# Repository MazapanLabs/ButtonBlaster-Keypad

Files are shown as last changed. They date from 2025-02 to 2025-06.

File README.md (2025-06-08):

# ButtonBlaster-Keypad

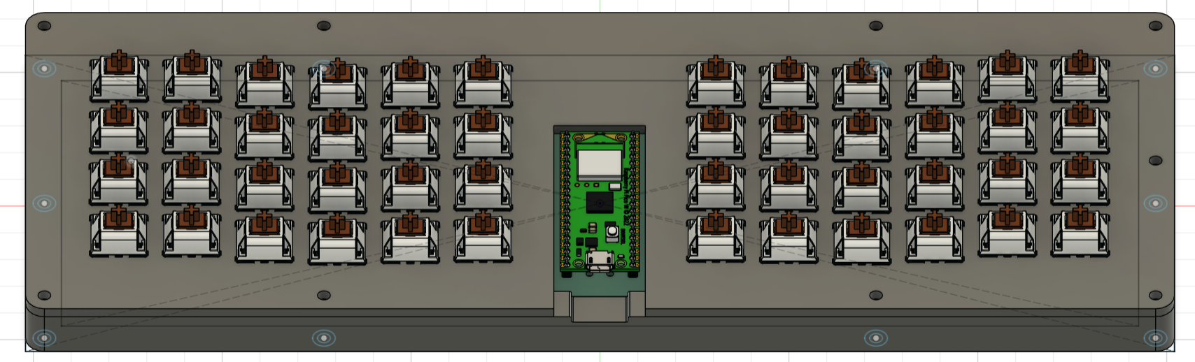
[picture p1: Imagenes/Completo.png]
Model


ButtonBlaster is a compact 48-key keypad based on the Orpheus Pico microcontroller and designed to work with the KMK firmware. The project was inspired by an ergonomic keyboard shown in a video by Joe Scotto. The PCB was custom-designed and paired with a 3D-printed case. It uses Gateron mechanical switches and discrete diodes.

## 🎥 Inspiration

Design inspired by a keyboard featured in a video by Joe Scotto:  
https://youtu.be/sMTs8F6Fk6s?si=EPKrmchUF-LIuJZo

---

## 📦 Specifications

### 🔩 Bill of Materials (BOM)

| Quantity | Component | Link |
|---|---|---|
| 48x | Gateron KS-3X1 Milky Switch | [Keychron](https://www.keychron.mx/products/gateron-ks-3x1-milky-switch?variant=45655197909205) |
| 48x | Keycaps | [Keychron](https://www.keychron.mx/products/keychron-k12-keycap-set?variant=45655109271765) |
| 48x | Diodes 1N4148 | [UElectronics](https://uelectronics.com/producto/kit-de-100-diodos-1n5399-1n5408-1n4148-1n4007-1n5819-1n5822/) |
| 1x | Orpheus Pico | — |
| 1x | Custom PCB | — |
| 10x | M3 brass heatsets | [UElectronics](https://uelectronics.com/producto/rosca-de-laton-m2-m3-m4/) |
| 10x | M3x12 screws | [MercadoLibre](https://articulo.mercadolibre.com.mx/MLM-3383497816-tornillo-m3-de-cruz-12mm-100pzs-_JM) |

### 🧰 Other files

- Firmware: **KMK**
- STL files:
  - `ButtonBlaster-Keypad_Top.stl`
  - `ButtonBlaster-Keypad_Bottom.stl`

---

## 📷 Project Images

### 🔌 Schematic
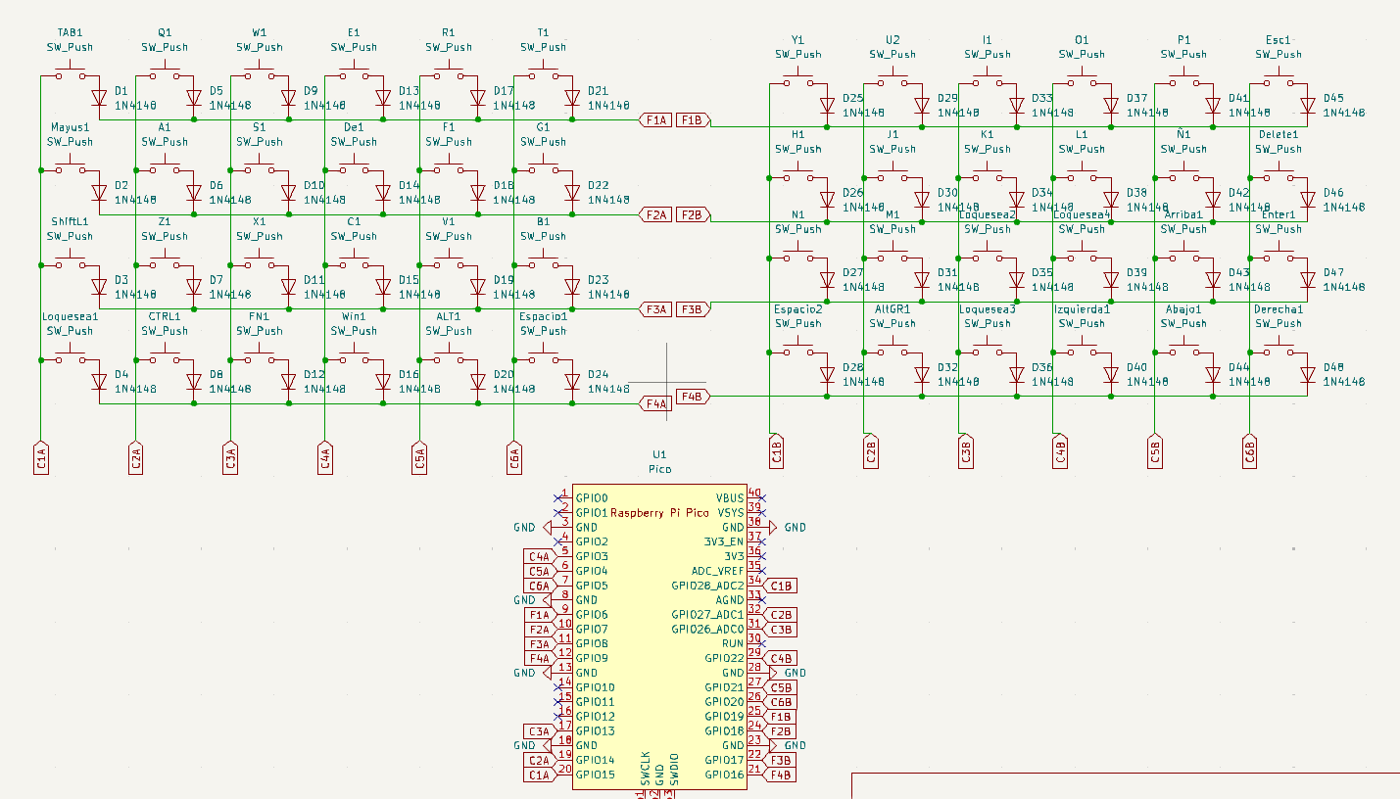
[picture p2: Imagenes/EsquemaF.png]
Schematic


### 🧠 PCB
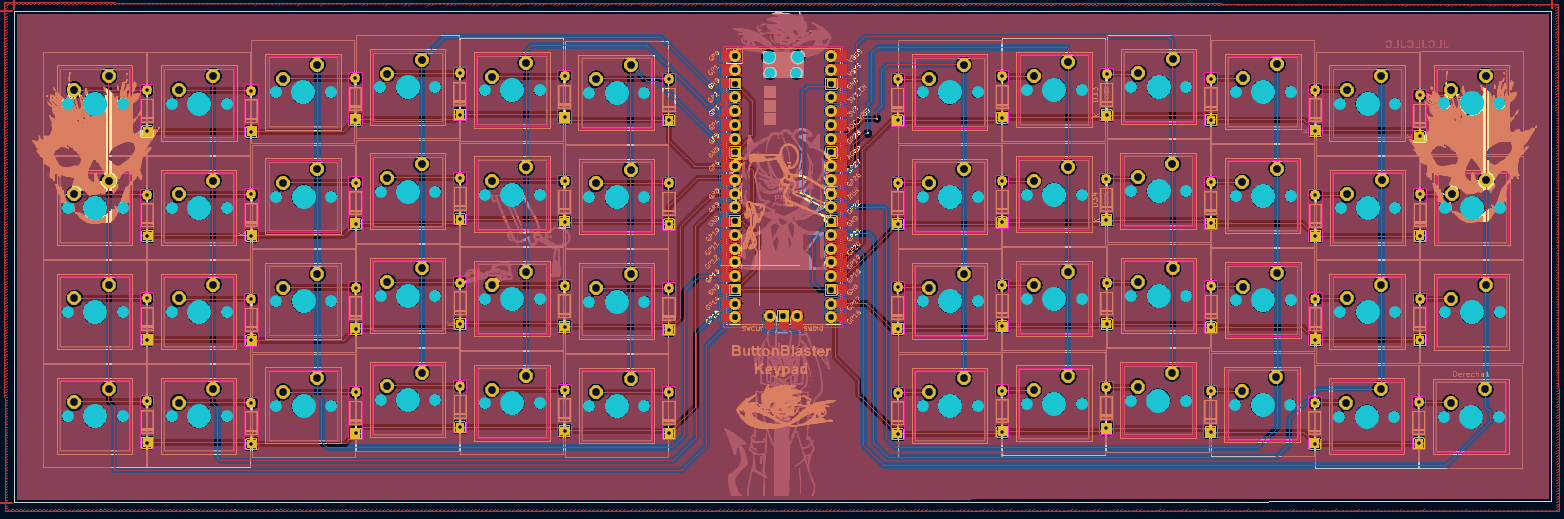
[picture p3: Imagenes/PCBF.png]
PCB


### 🧱 Case
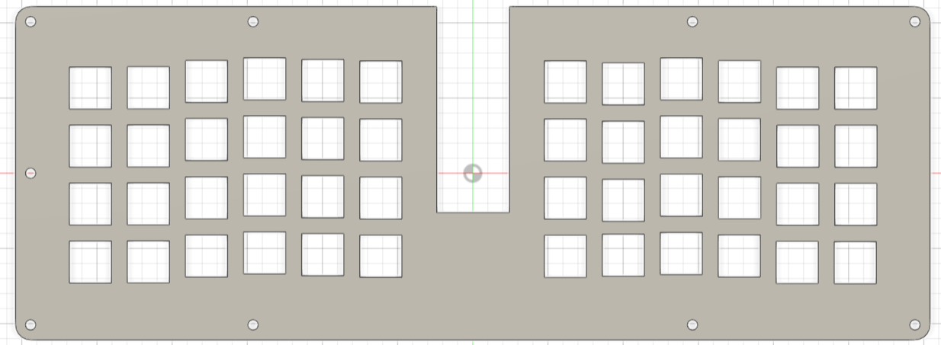
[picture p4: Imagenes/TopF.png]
CaseT

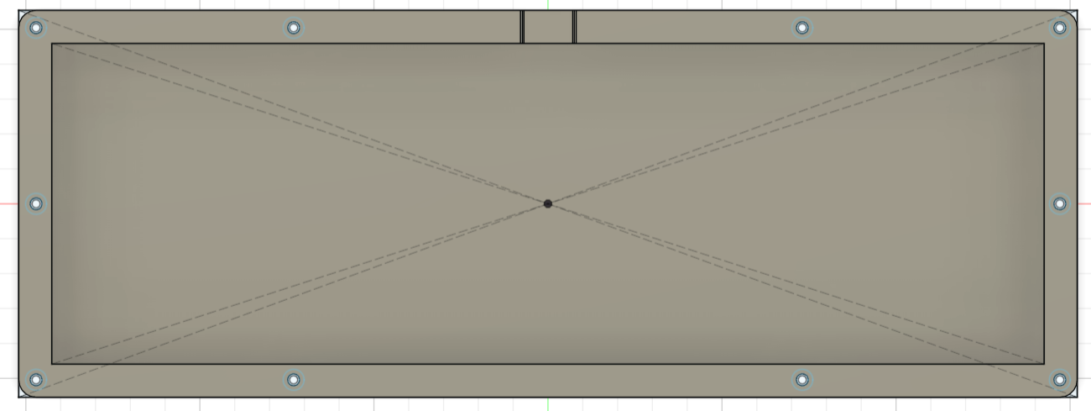
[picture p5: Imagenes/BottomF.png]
CaseB


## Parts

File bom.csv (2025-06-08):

Designator | Footprint | Quantity | Value | LCSC Part #
A1, ABAJO1, ALT1, ALTGR1, ARRIBA1, B1, C1, CTRL1, DE1, DELETE1, DERECHA1, E1, ENTER1, ESC1, ESPACIO1, ESPACIO2, F1, FN1, G1, H1, I1, IZQUIERDA1, J1, K1, L1, LOQUESEA1, LOQUESEA2, LOQUESEA3, LOQUESEA4, M1, MAYUS1, N1, O1, P1, Q1, R1, S1, SHIFTL1, T1, TAB1, U2, V1, W1, WIN1, X1, Y1, Z1, Ñ1 | SW_Cherry_MX_1.00u_PCB | 48 | SW_Push
D1, D10, D11, D12, D13, D14, D15, D16, D17, D18, D19, D2, D20, D21, D22, D23, D24, D25, D26, D27, D28, D29, D3, D30, D31, D32, D33, D34, D35, D36, D37, D38, D39, D4, D40, D41, D42, D43, D44, D45, D46, D47, D48, D5, D6, D7, D8, D9 | D_DO-35_SOD27_P7.62mm_Horizontal | 48 | 1N4148
U1 | RPi_Pico_SMD_TH | 1 | Pico

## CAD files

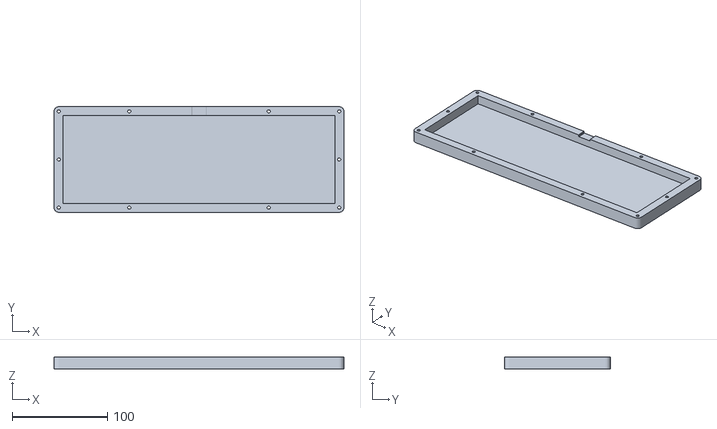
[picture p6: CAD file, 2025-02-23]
Production/BB-K Bottom_.stl
304.1 x 110.8 x 13.0

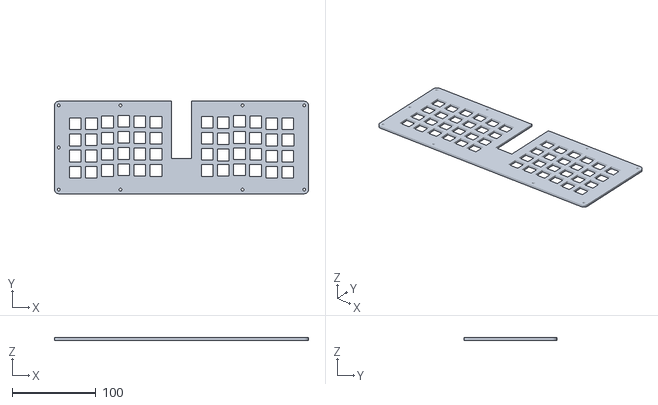
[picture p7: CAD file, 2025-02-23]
Production/BB-K Top.stl
304.1 x 110.8 x 3.00

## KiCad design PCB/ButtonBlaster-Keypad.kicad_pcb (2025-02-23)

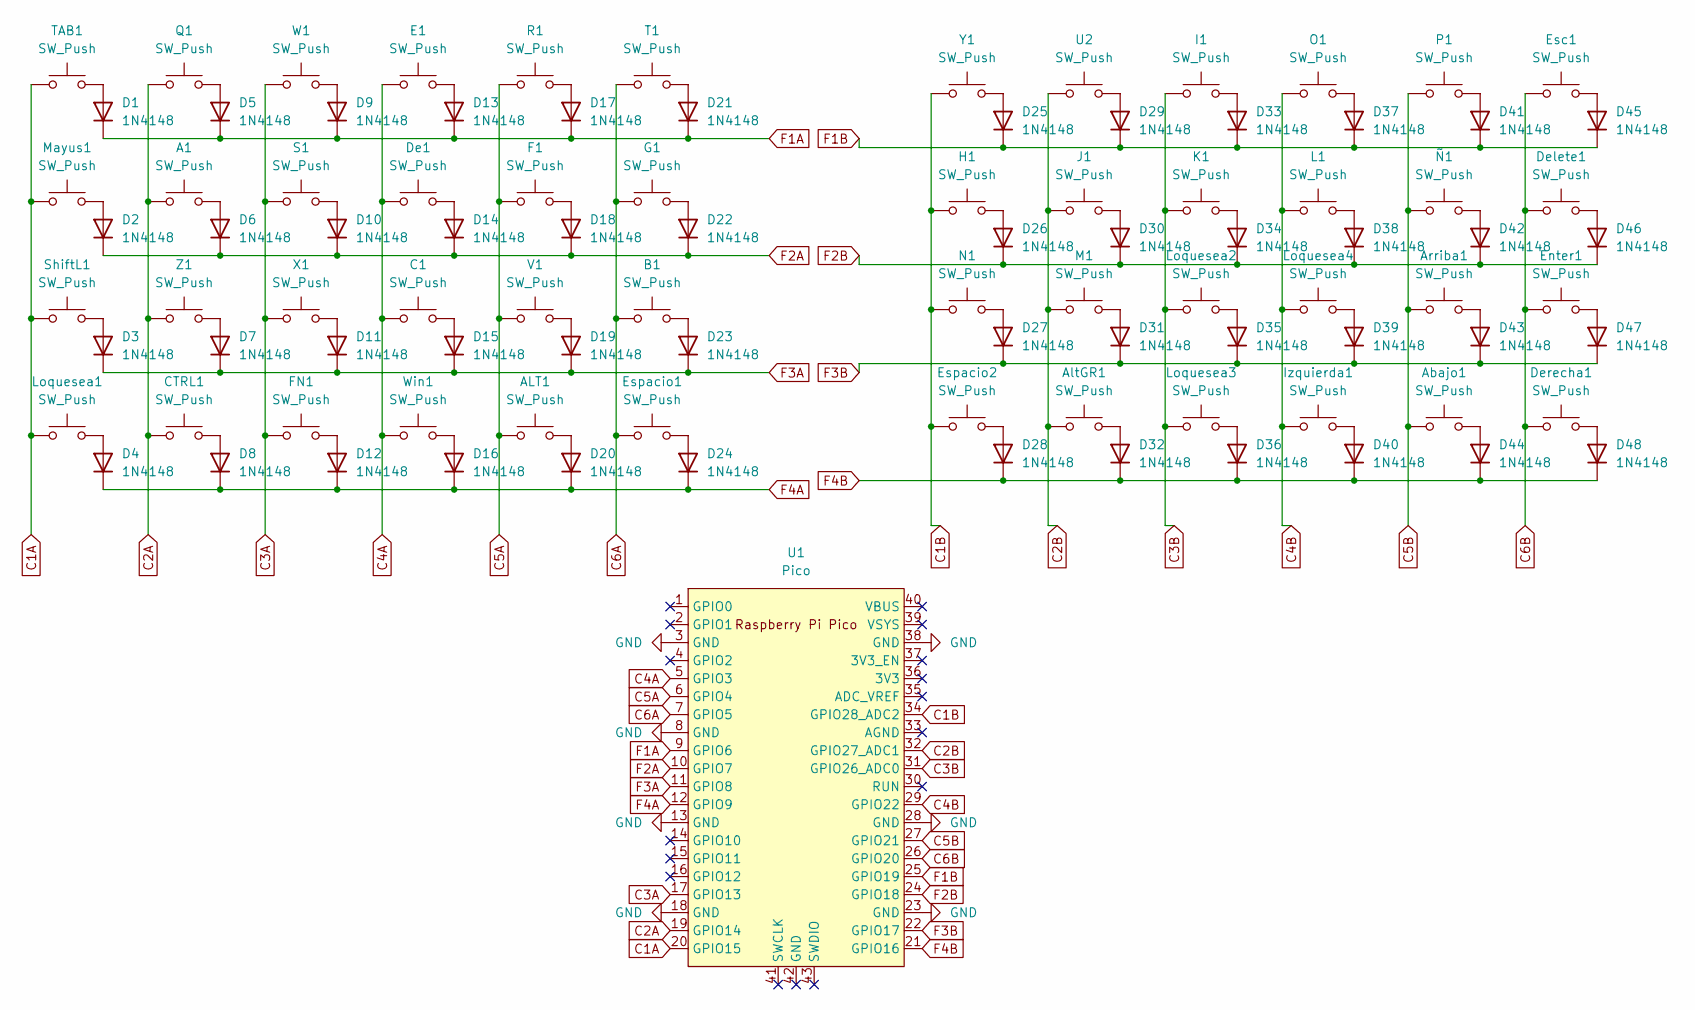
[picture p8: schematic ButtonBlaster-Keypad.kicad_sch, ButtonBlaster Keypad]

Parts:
A1: SW_Push; SW_Cherry_MX_1.00u_PCB
ALT1: SW_Push; SW_Cherry_MX_1.00u_PCB
Abajo1: SW_Push; SW_Cherry_MX_1.00u_PCB
AltGR1: SW_Push; SW_Cherry_MX_1.00u_PCB
Arriba1: SW_Push; SW_Cherry_MX_1.00u_PCB
B1: SW_Push; SW_Cherry_MX_1.00u_PCB
C1: SW_Push; SW_Cherry_MX_1.00u_PCB
CTRL1: SW_Push; SW_Cherry_MX_1.00u_PCB
D1, D2, D3, D4, D5, D6, D7, D8, D9, D10, D11, D12, D13, D14, D15, D16, D17, D18, D19, D20, D21, D22, D23, D24, D25, D26, D27, D28, D29, D30, D31, D32, D33, D34, D35, D36, D37, D38, D39, D40, D41, D42, D43, D44, D45, D46, D47, D48: 1N4148; D_DO-35_SOD27_P7.62mm_Horizontal
De1: SW_Push; SW_Cherry_MX_1.00u_PCB
Delete1: SW_Push; SW_Cherry_MX_1.00u_PCB
Derecha1: SW_Push; SW_Cherry_MX_1.00u_PCB
E1: SW_Push; SW_Cherry_MX_1.00u_PCB
Enter1: SW_Push; SW_Cherry_MX_1.00u_PCB
Esc1: SW_Push; SW_Cherry_MX_1.00u_PCB
Espacio1, Espacio2: SW_Push; SW_Cherry_MX_1.00u_PCB
F1: SW_Push; SW_Cherry_MX_1.00u_PCB
FN1: SW_Push; SW_Cherry_MX_1.00u_PCB
G1: SW_Push; SW_Cherry_MX_1.00u_PCB
H1: SW_Push; SW_Cherry_MX_1.00u_PCB
I1: SW_Push; SW_Cherry_MX_1.00u_PCB
Izquierda1: SW_Push; SW_Cherry_MX_1.00u_PCB
J1: SW_Push; SW_Cherry_MX_1.00u_PCB
K1: SW_Push; SW_Cherry_MX_1.00u_PCB
L1: SW_Push; SW_Cherry_MX_1.00u_PCB
Loquesea1, Loquesea2, Loquesea3, Loquesea4: SW_Push; SW_Cherry_MX_1.00u_PCB
M1: SW_Push; SW_Cherry_MX_1.00u_PCB
Mayus1: SW_Push; SW_Cherry_MX_1.00u_PCB
N1: SW_Push; SW_Cherry_MX_1.00u_PCB
O1: SW_Push; SW_Cherry_MX_1.00u_PCB
P1: SW_Push; SW_Cherry_MX_1.00u_PCB
Q1: SW_Push; SW_Cherry_MX_1.00u_PCB
R1: SW_Push; SW_Cherry_MX_1.00u_PCB
S1: SW_Push; SW_Cherry_MX_1.00u_PCB
ShiftL1: SW_Push; SW_Cherry_MX_1.00u_PCB
T1: SW_Push; SW_Cherry_MX_1.00u_PCB
TAB1: SW_Push; SW_Cherry_MX_1.00u_PCB
U1: Pico; RPi_Pico_SMD_TH
U2: SW_Push; SW_Cherry_MX_1.00u_PCB
V1: SW_Push; SW_Cherry_MX_1.00u_PCB
W1: SW_Push; SW_Cherry_MX_1.00u_PCB
Win1: SW_Push; SW_Cherry_MX_1.00u_PCB
X1: SW_Push; SW_Cherry_MX_1.00u_PCB
Y1: SW_Push; SW_Cherry_MX_1.00u_PCB
Z1: SW_Push; SW_Cherry_MX_1.00u_PCB
Ñ1: SW_Push; SW_Cherry_MX_1.00u_PCB

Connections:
C1A: Loquesea1.1, Mayus1.1, ShiftL1.1, TAB1.1, U1.20 (GPIO15)
C1B: Espacio2.1, H1.1, N1.1, U1.34 (GPIO28_ADC2), Y1.1
C2A: A1.1, CTRL1.1, Q1.1, U1.19 (GPIO14), Z1.1
C2B: AltGR1.1, J1.1, M1.1, U1.32 (GPIO27_ADC1), U2.1
C3A: FN1.1, S1.1, U1.17 (GPIO13), W1.1, X1.1
C3B: I1.1, K1.1, Loquesea2.1, Loquesea3.1, U1.31 (GPIO26_ADC0)
C4A: C1.1, De1.1, E1.1, U1.5 (GPIO3), Win1.1
C4B: Izquierda1.1, L1.1, Loquesea4.1, O1.1, U1.29 (GPIO22)
C5A: ALT1.1, F1.1, R1.1, U1.6 (GPIO4), V1.1
C5B: Abajo1.1, Arriba1.1, P1.1, U1.27 (GPIO21), Ñ1.1
C6A: B1.1, Espacio1.1, G1.1, T1.1, U1.7 (GPIO5)
C6B: Delete1.1, Derecha1.1, Enter1.1, Esc1.1, U1.26 (GPIO20)
F1A: D1.1 (K), D5.1 (K), D9.1 (K), D13.1 (K), D17.1 (K), D21.1 (K), U1.9 (GPIO6)
F1B: D25.1 (K), D29.1 (K), D33.1 (K), D37.1 (K), D41.1 (K), D45.1 (K), U1.25 (GPIO19)
F2A: D2.1 (K), D6.1 (K), D10.1 (K), D14.1 (K), D18.1 (K), D22.1 (K), U1.10 (GPIO7)
F2B: D26.1 (K), D30.1 (K), D34.1 (K), D38.1 (K), D42.1 (K), D46.1 (K), U1.24 (GPIO18)
F3A: D3.1 (K), D7.1 (K), D11.1 (K), D15.1 (K), D19.1 (K), D23.1 (K), U1.11 (GPIO8)
F3B: D27.1 (K), D31.1 (K), D35.1 (K), D39.1 (K), D43.1 (K), D47.1 (K), U1.22 (GPIO17)
F4A: D4.1 (K), D8.1 (K), D12.1 (K), D16.1 (K), D20.1 (K), D24.1 (K), U1.12 (GPIO9)
F4B: D28.1 (K), D32.1 (K), D36.1 (K), D40.1 (K), D44.1 (K), D48.1 (K), U1.21 (GPIO16)
GND: U1.3 (GND), U1.8 (GND), U1.13 (GND), U1.18 (GND), U1.23 (GND), U1.28 (GND), U1.38 (GND)
unnamed: D1.2 (A), TAB1.2
unnamed: D2.2 (A), Mayus1.2
unnamed: D3.2 (A), ShiftL1.2
unnamed: D4.2 (A), Loquesea1.2
unnamed: D5.2 (A), Q1.2
unnamed: A1.2, D6.2 (A)
unnamed: D7.2 (A), Z1.2
unnamed: CTRL1.2, D8.2 (A)
unnamed: D9.2 (A), W1.2
unnamed: D10.2 (A), S1.2
unnamed: D11.2 (A), X1.2
unnamed: D12.2 (A), FN1.2
unnamed: D13.2 (A), E1.2
unnamed: D14.2 (A), De1.2
unnamed: C1.2, D15.2 (A)
unnamed: D16.2 (A), Win1.2
unnamed: D17.2 (A), R1.2
unnamed: D18.2 (A), F1.2
unnamed: D19.2 (A), V1.2
unnamed: ALT1.2, D20.2 (A)
unnamed: D21.2 (A), T1.2
unnamed: D22.2 (A), G1.2
unnamed: B1.2, D23.2 (A)
unnamed: D24.2 (A), Espacio1.2
unnamed: D25.2 (A), Y1.2
unnamed: D26.2 (A), H1.2
unnamed: D27.2 (A), N1.2
unnamed: D28.2 (A), Espacio2.2
unnamed: D29.2 (A), U2.2
unnamed: D30.2 (A), J1.2
unnamed: D31.2 (A), M1.2
unnamed: AltGR1.2, D32.2 (A)
unnamed: D33.2 (A), I1.2
unnamed: D34.2 (A), K1.2
unnamed: D35.2 (A), Loquesea2.2
unnamed: D36.2 (A), Loquesea3.2
unnamed: D37.2 (A), O1.2
unnamed: D38.2 (A), L1.2
unnamed: D39.2 (A), Loquesea4.2
unnamed: D40.2 (A), Izquierda1.2
unnamed: D41.2 (A), P1.2
unnamed: D42.2 (A), Ñ1.2
unnamed: Arriba1.2, D43.2 (A)
unnamed: Abajo1.2, D44.2 (A)
unnamed: D45.2 (A), Esc1.2
unnamed: D46.2 (A), Delete1.2
unnamed: D47.2 (A), Enter1.2
unnamed: D48.2 (A), Derecha1.2

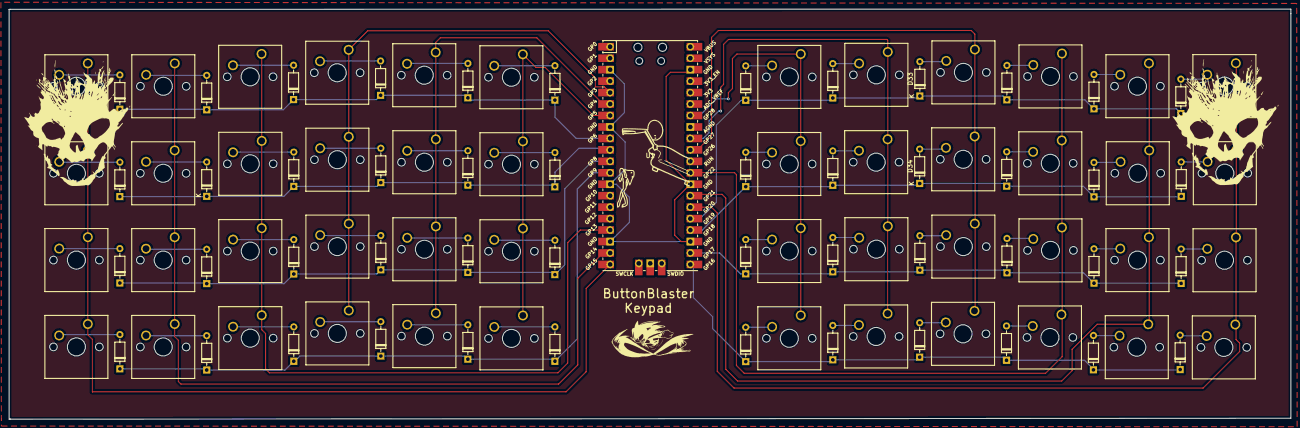
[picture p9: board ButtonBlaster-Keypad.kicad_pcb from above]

Board: 2 copper layers, 284.1 x 90.9 mm, 97 parts (0 on the bottom side), 69 nets.
